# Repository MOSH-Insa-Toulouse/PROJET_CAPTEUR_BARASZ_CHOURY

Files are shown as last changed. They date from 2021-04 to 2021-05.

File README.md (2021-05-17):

# PROJET_CAPTEUR_BARASZ_CHOURY
 
## SOMMAIRE 
* 1 [Introduction](#introduction)
* 2 [Installation de la chaine de mesure](#paragraph2)
* 3 [Modélisation de la carte PCB sur KiCad](#paragraph3)
* 4 [Fabrication du shield et soudure des composants](#paragraph4)
* 5 [Arduino UNO](#paragraph5) 
    *  5.1 [Description du code](#subparagraph5.1) 
    *  5.2 [Bibliothèques Arduino](#subparagraph5.2)
* 6 [Application APK](#paragraph6)
* 7 [Mise en oeuvre du banc de test](#paragraph7)
    *  7.1 [Protocole](#paragraph7.1)
    *  7.2 [Résultats obtenus](#paragraph7.2)
* 8 [Améliorations à apporter](#paragraph8)

--------- 
## Introduction 
2020-2021 : Ce projet a été réalisé dans le cadre de l'unité de formation _"Du capteur au banc de test"_ de 4ième année Génie Physique à l'INSA Toulouse.
L’objectif est la conception d’un capteur de déformation (jauge de déformation) à base de graphite, peu coûteux, flexible, léger, et avant tout écoresponsable. 

Le coloriage au crayon laisse une fine couche de graphite sur le papier. Cette couche de graphite possède un réseau percolé caractéristique. Toute déformation de ce réseau induit une variation de la distance entre les nanoparticules de graphite. Cette dernière est à l’origine de la modification de la conductivité électrique/résistance de la couche de graphite. 

Souhaitant acquérir et exploiter le signal associé à la résistance du capteur, nous avons réalisé un shield PCB, à l’aide du logiciel KiCad contenant un amplificateur transimpédance, des interfaces pour un module bluetooth, un écran OLED, et un encordeur rotatoir. Ce shiled PCB est ensuite inséré sur un microcontrôleur Arduino Uno, programmé à l’aide du logiciel Arduino IDE en C++. Les mesures de résistances sont également transmises par Bluetooth et répertoriées sur notre application android APK créée sur MIT App Inventor. 

La chaîne de mesure fin prête, nous avons mis au point un banc de test permettant l'étude de la variation relative de la résistance de différents type de capteurs lors de déformation en compression et tension. 

--------------------

## Installation de la chaine de mesure 

    - Imprimer le PCB, préalablement designé sur KiCad, grâce à l'empreinte Gerber. 
  
    - Vérifier l'état des pistes. 
  
    - Souder les composants et brancher l'OLED, l'encodeur rotatoir et le module Bluetooth. 
  
    - Connecter le PCB sur la carte Arduino Uno.
  
    - Connecter le microcontrolleur Arduino Uno au PC grâce au cable USB. 
  
    - Ouvrir le programme Arduino (voir dossier Arduino).   
      Sélectionner au préalable le bon port de communication Arduino puis compiler et téléverser le programme. 
  
Les valeurs de résistance/tension sont directement affichées sur l'écran OLED. Grâce à l'encodeur rotatoir, vous pouvez décider d'afficher la grandeur souhaitée. Ces dernières sont aussi disponibles sur le moniteur Arduino.
Vous pouvez aussi télécharger notre application APK pour obtenir directement les valeurs sur votre smartphone grâce à votre connexion Bluetooth. 

-------------------

## Modélisation de la carte PCB sur KiCad 

Réalisation de la carte PCB sur KiCad  
   
    - Creation des symboles de l'OLED, le module bluetooth, l'encodeur rotatoir et le capteur graphite.
      Tous les symboles sont répertoriés dans le dossier KiCad. 

    - Schéma electrique du circuit sur eeschema. Sur ce shéma, vous trouverez un amplificateur transimpédance,
      l'écran OLED, le module Bluetooth et l'encodeur rotatoire. En haut à droite les pins de la carte Arduino
      sont représentées.  
Capture d’écran 2021-04-20 à 10 19 14

    - Routage des pistes sur pcbnew.

Visualisation 2D du shield 

Capture d’écran 2021-04-20 à 10 38 54
   
Visualisation 3D du shield

Capture d’écran 2021-04-20 à 10 42 33

-------------------

## Fabrication du shield et soudure des composants 

Avec l'aide de Mme Cathy Crouzet, nous avons fabriqué la carte PCB modélisée au préalable sur le logiciel KiCad. Notre carte PCB est constituée d'une plaque isolante d'epoxy recouverte d'une très fine feuille de cuivre. Une couche de résine photosensible est déposée sur ce support epoxy cuivré.

Tout d'abord, le tracé de notre modélisation PCB est imprimé sur un support transparant aux ultraviolets de type papier calque : on obtient le masque (ou typon). Celui ci est placé sur la plaquette epoxy, dans l'insoleuse à tube UV, en prenant soin de poser le côté encré au contact du cuivre. Lors de l'insolation de la plaque (réalisée en 1'30"- 2'30"), les parties du typon correspondant aux pistes du circuit empêchent les UV d'atteindre la surface sensible.   
La plaque est ensuite plongée quelques secondes dans un liquide appelé révélateur. Celui ci dissout la résine exposée aux UV lors de l'insolation. A la fin de cette étape, la résine est seulement conservée dans les zones destinées aux pistes de notre circuit.

Après une étape de rinçage à l'eau courante, la plaquette doit par la suite être gravée. Pour cela, nous la plongeons dans un bain de perchlorure de fer pendant 10 minutes environ. Les parties de cuivre non protégées par la résine photosensible sont ici dissoues. Enfin, la dernière étape du processus consiste à retirer l'excès de résine en utilisant de l'acétone. 

La carte PCB ainsi obtenue est fin prête pour les étapes de perçage et de mise en place des composants. 

  * Perçage des trous de la plaque obtenugrâce à une perçeuse électrique 
Nous perçons des trous de diamètre égale à :
      * 0.8mm pour l'AOP, les résistances et les capacités.
      * 1mm pour les connecteurs de l'Arduino, le module Bluetooth, l'écran OLED, l'encodeur rotatoire et les pinces du capteur.
 
  * Soudure des composants
 
Les composants sont soudés sur la carte PCB à l'aide d'un fer à souder. 
 
----------------------

## Arduino UNO 

### Description du code 

Le code Arduino permet de lire les valeurs de tension du capteur de graphite et calcule la valeur de résistance correspondante. Il assure l'affichage des valeurs de tension et de résistance sur un écran OLED. De plus, le code permet la gestion d'un menu via l'encodeur rotatoire: l'utilisateur peut décider d'afficher la valeur de la résistance ou bien celle de la tension. 

Le code permet aussi de communiquer par Bluetooth avec le télephone portable grâce. Il envoie la mesure de la tension du capteur de graphite par Bluetooth. 

### Bibliothèques Arduino 

Afin d'utiliser le code Arduino, il vous faudra au préalable télécharger des bibliothèques Arduino.

À installer depuis l'IDE ou GitHub :

- Adafruit GFX Library : https://github.com/adafruit/Adafruit-GFX-Library
- Adafruit SSD1306 : https://github.com/adafruit/Adafruit_SSD1306
- Adafruit BusIO : https://github.com/adafruit/Adafruit_BusIO  

Vous pouvez aussi télécharger ces bibliothèques direcetement sur l'application Arduino

1) Dans l’IDE Arduino cliquez sur "croquis", allez sur "inclure un bibliothèque" puis cliquez sur  "Gerer les bibliothèques".  

Capture d’écran 2021-04-21 à 09 37 15

2) Une fenêtre apparait. Tappez le nom de la bibliothèques que vous voulez ajouter dans la barre de recherche et cliquez sur  "Installer".Fermez la fenêtre.  
   
Capture d’écran 2021-04-21 à 09 36 37

3) Dans l’IDE Arduino cliquez sur "croquis", allez sur "inclure un bibliothèque". A la fin dans les "bibliothèques contribuées" doit se trouver votre biblothèques téléchargée.  

Capture d’écran 2021-04-21 à 09 40 34

4) Afin de savoir comment fonctionne la bibliothèque installée, vous pourrez vous servir de la page d’aide qui accompagne généralement la bibliothèque ou alors vous aider des exemples fournis avec celle-ci disponible ici :  

Capture d’écran 2021-04-21 à 09 43 44

------------------------------

## Application APK 

L'application APK est une applictaion pour smartphone utilisant le système d'exploitation Android. 
Vous pouvez télecharger l'application grâce au fichier .apk qui vous est fourni dans notre dossier APK Bluetooth.  
Si vous souhaitez modifier l'application, vous pouvez utiliser le fichier .aia sur l'application en ligne _MIT APP INVENTOR_.  

Notre application est à mettre en relation avec le code Arduino développé pour mesurer la tension de la couche de graphite. L'application permet de :
  * se connecter à un module Bluetooth.
  * une fois connecté, relever la  valeur de la tension de la couche de graphite envoyée par Bluetooth.
  * calculer la résistance correspondante.
  * afficher ces deux valeurs de tension et de résistance
  * tracer un graphe décrivant l'évolution de la tension au cours du temps.  

app

----------------------------

## Mise en oeuvre du banc de test  

### Protocole 

Le protocole du banc de test est détaillé dans le fichier "Protocole du banc de test". Veuillez trouver ci joint le lien de ce fichier :https://github.com/MOSH-Insa-Toulouse/PROJET_CAPTEUR_BARASZ_CHOURY/blob/c4a42f93ef4b2496bb2e2b371ca4b9b335598a01/Banc%20de%20test/Protocole%20de%20notre%20banc%20de%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

### Résultats obtenus 

Résultats obtenus sont détaillés au lien suivant : https://github.com/MOSH-Insa-Toulouse/PROJET_CAPTEUR_BARASZ_CHOURY/blob/7fd93865a4fc5e2c620f3dd2ebc7bdd68492d652/Banc%20de%20test/R%C3%A9sultats%20Banc%20de%20Test.x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 

Les analyses de nos résultats : https://github.com/MOSH-Insa-Toulouse/PROJET_CAPTEUR_BARASZ_CHOURY/blob/7fd93865a4fc5e2c620f3dd2ebc7bdd68492d652/Banc%20de%20test/Analyse%20de%20nos%20r%C3%A9sultats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 

----------------------------

## Améliorations à apporter  
 
Notre banc de test présente certaines limites. On peut critiquer notamment : 
   - le dépôt de graphite sur le papier : on ne peut maitriser la quantité de graphite déposée sur le papier, la précision du coloriage.
   - la non répétabilité de la mesure. En effet, entre chaque série de mesures, les déformations appliquées peuvent varier: le banc de test ne permet pas d’appliquer une       déformation identique. On pourrait envisager un banc de test fonctionnant avec un servomoteur par exemple. Ce système permet de générer des contraintes avec des consignes d’angles bien présice et d'obtenir, de ce fait, une meilleure reproductibilité. 
   - la déformation irréversible du capteur entre chaque série de mesures. 

Notre carte shield peut être également améliorée. En effet, afin de pouvoir lire une plus grande plage de résistance tout en ayant des mesures stables, il faudrait pouvoir changer le gain du circuit transimpédance c'est à dire modifier la résistance R2 (voir schéma KiCad ). Cependant nous l'avons soudée sur le circuit PCB. Il aurait donc fallu : 
    
   - ne pas souder cette résistance pour pouvoir mettre des résistances différentes
   - souder une résistance variable (potentiomètre).   

Un code Arduino plus complet pourrait également être développé. Si nous travaillons avec une résistance R2 variable, le code doit prendre en compte la modification de la valeur de R2. Le code Arduino pourrait gérer un encodeur rotatoire permttant de modifier la valeur de R2 dans le code.

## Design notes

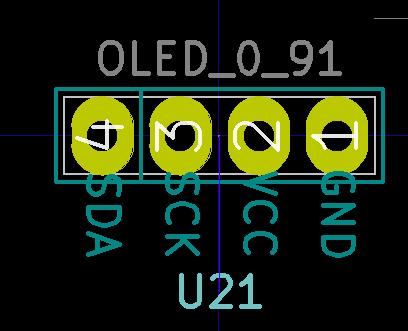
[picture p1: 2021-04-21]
KiCad/OLED/empreinte_OLED.png

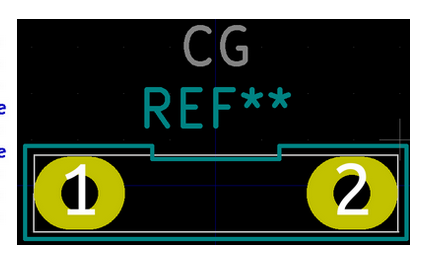
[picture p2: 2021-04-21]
KiCad/Capteur/empreinte_capteur.png

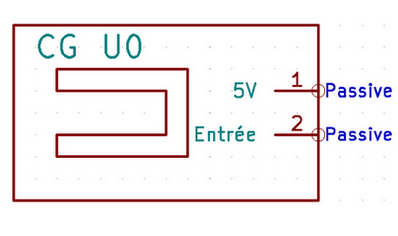
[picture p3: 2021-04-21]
KiCad/Capteur/schema_capteur.png

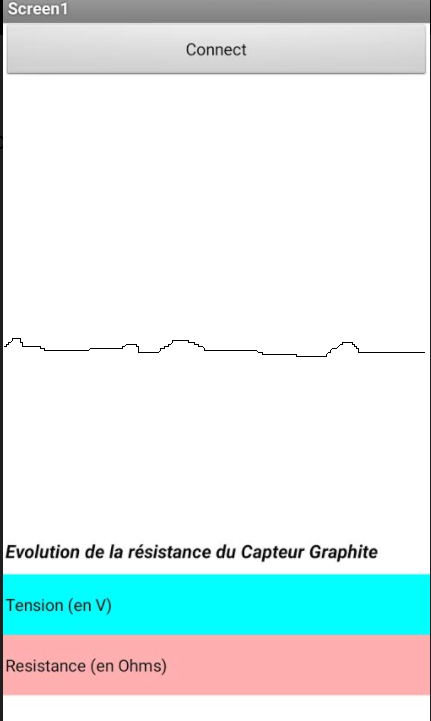
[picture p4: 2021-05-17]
APK Bluetooth/app.png

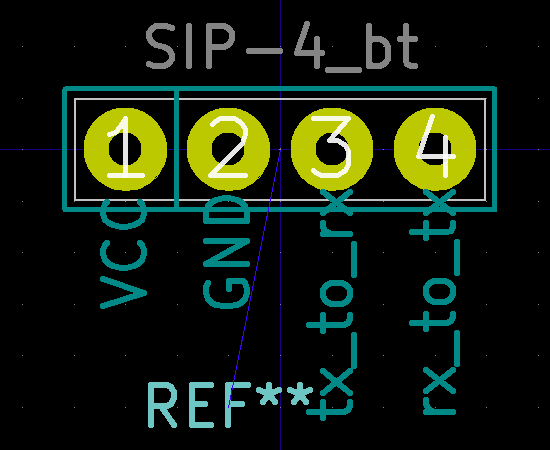
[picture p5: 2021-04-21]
KiCad/Module bluetooth/empreinte_module_bt.png

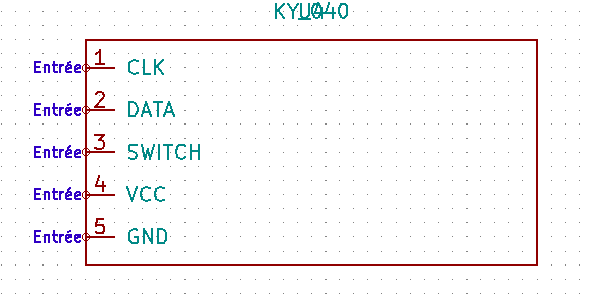
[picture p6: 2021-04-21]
KiCad/Encodeur Rotatoir/schema_encodeur.png

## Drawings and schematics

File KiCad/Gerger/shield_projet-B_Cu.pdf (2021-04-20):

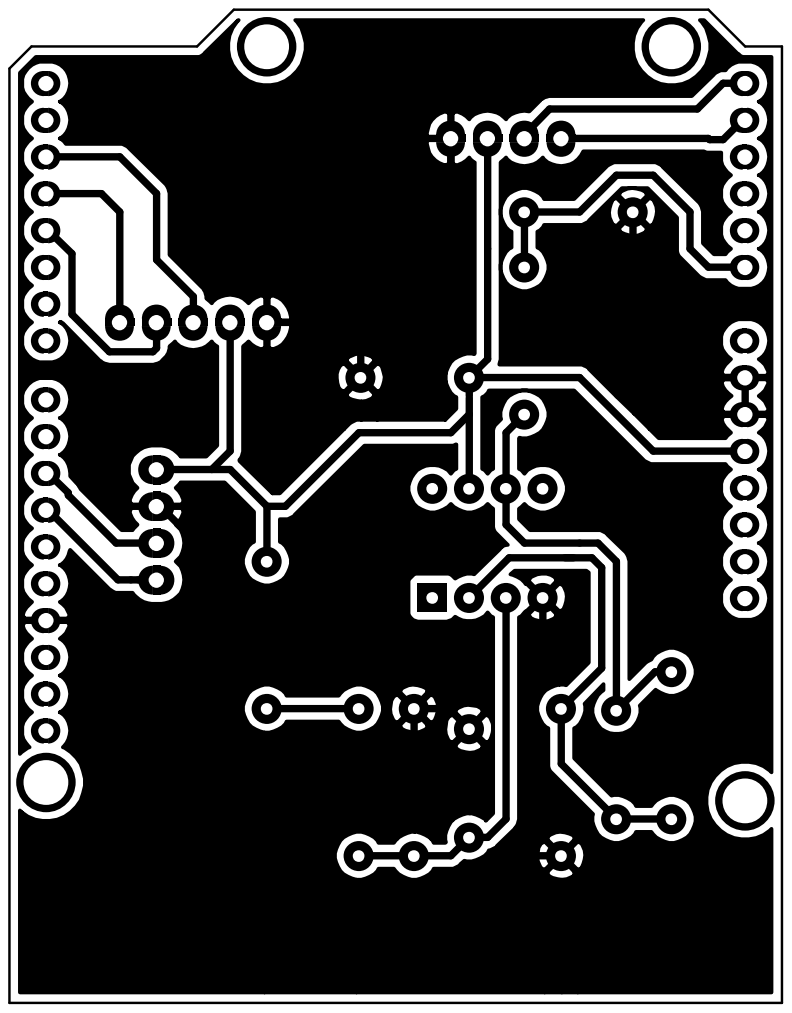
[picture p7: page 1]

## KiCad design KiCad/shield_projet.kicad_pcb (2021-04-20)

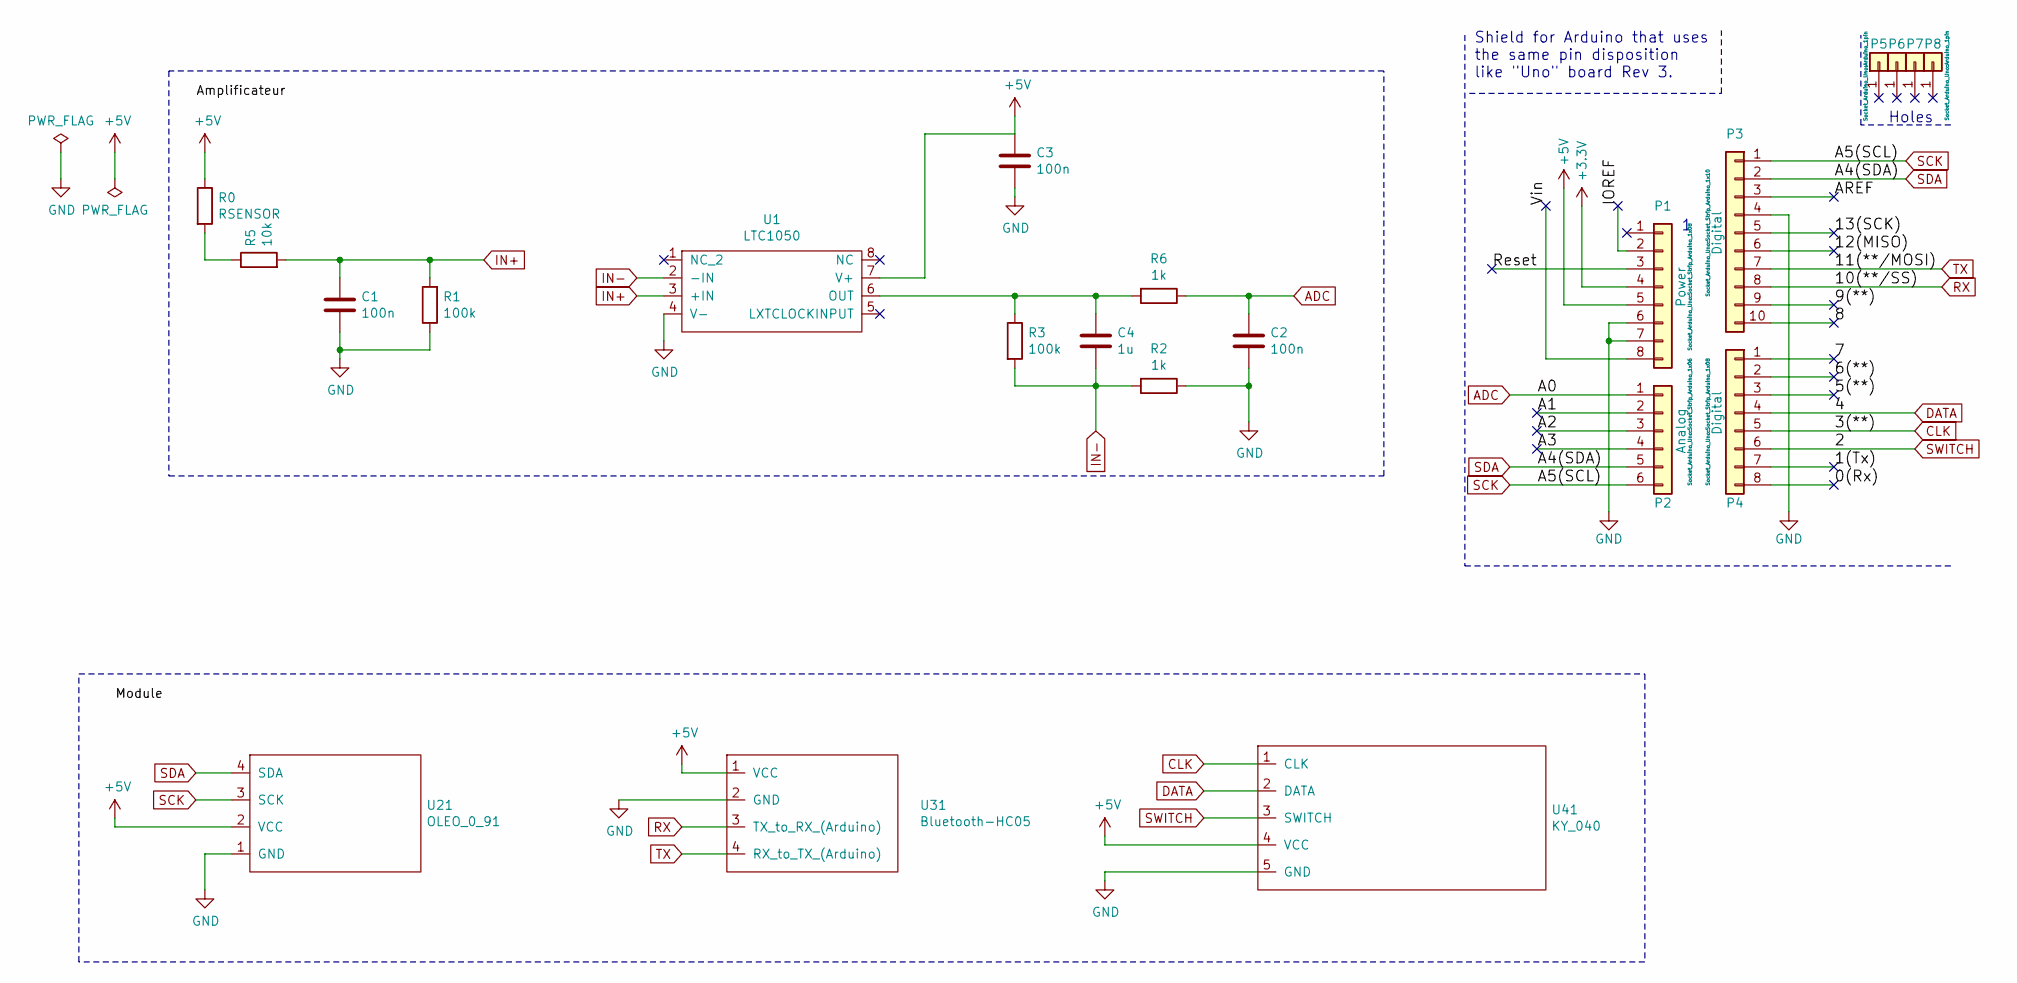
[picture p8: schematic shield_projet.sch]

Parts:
C1, C2, C3: 100n; C_Axial_L5.1mm_D3.1mm_P7.50mm_Horizontal
C4: 1u; C_Axial_L5.1mm_D3.1mm_P7.50mm_Horizontal
P1: Power; Socket_Strip_Arduino_1x08
P2: Analog; Socket_Strip_Arduino_1x06
P3: Digital; Socket_Strip_Arduino_1x10
P4: Digital; Socket_Strip_Arduino_1x08
P5, P6, P7, P8: CONN_01X01; Arduino_1pin
R0: RSENSOR; R_Axial_DIN0207_L6.3mm_D2.5mm_P10.16mm_Horizontal
R1, R3: 100k; R_Axial_DIN0207_L6.3mm_D2.5mm_P10.16mm_Horizontal
R2, R6: 1k; R_Axial_DIN0207_L6.3mm_D2.5mm_P10.16mm_Horizontal
R5: 10k; R_Axial_DIN0207_L6.3mm_D2.5mm_P10.16mm_Horizontal
U1: LTC1050; DIP-8_296
U21: OLEO_0_91; SIP-4
U31: Bluetooth-HC05; SIP-4_bt
U41: KY_040; SIP-5

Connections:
+3V3: P1.4
+5V: C3.1, P1.5, R0.1, U1.7 (V+), U21.2 (VCC), U31.1 (VCC), U41.4 (VCC)
/0(Rx): P4.8
/1(Tx): P4.7
/5(**): P4.3
/6(**): P4.2
/7: P4.1
/8: P3.10
/9(**): P3.9
/12(MISO): P3.6
/13(SCK): P3.5
/A1: P2.2
/A2: P2.3
/A3: P2.4
/AREF: P3.3
/IOREF: P1.2
/Reset: P1.3
/Vin: P1.8
ADC: C2.1, P2.1, R6.1
CLK: P4.5, U41.1 (CLK)
DATA: P4.4, U41.2 (DATA)
GND: C1.2, C2.2, C3.2, P1.6, P1.7, P3.4, R1.1, R2.1, U1.4 (V-), U21.1 (GND), U31.2 (GND), U41.5 (GND)
IN+: C1.1, R1.2, R5.2, U1.3 (+IN)
IN-: C4.2, R2.2, R3.2, U1.2 (-IN)
unnamed: C4.1, R3.1, R6.2, U1.6 (OUT)
unnamed: R0.2, R5.1
RX: P3.8, U31.3 (TX_to_RX_(Arduino))
SCK: P2.6, P3.1, U21.3 (SCK)
SDA: P2.5, P3.2, U21.4 (SDA)
SWITCH: P4.6, U41.3 (SWITCH)
TX: P3.7, U31.4 (RX_to_TX_(Arduino))

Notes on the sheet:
Holes
Shield for Arduino that uses the same pin disposition like "Uno" board Rev 3.

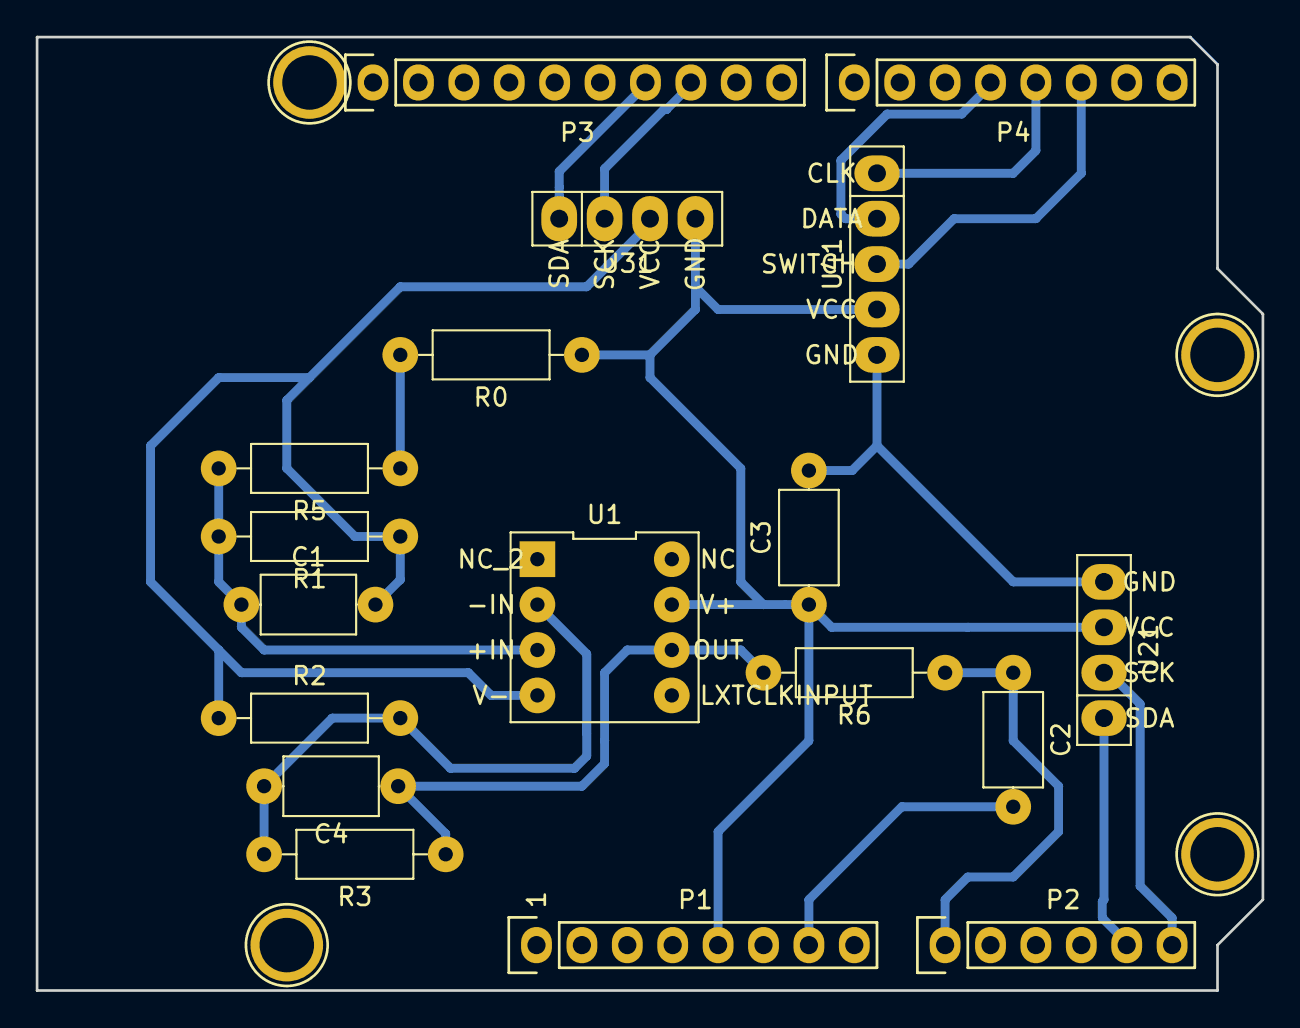
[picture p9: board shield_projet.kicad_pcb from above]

Board: 2 copper layers, 68.6 x 53.3 mm, 22 parts (0 on the bottom side), 14 nets.

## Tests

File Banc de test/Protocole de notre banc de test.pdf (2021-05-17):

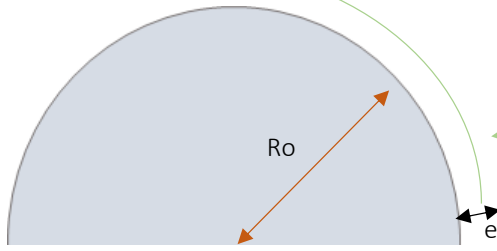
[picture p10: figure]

Ro : rayon de courbure du demi-cylindre à mesurer à l’aide d’une règle graduée.

### Protocole de notre banc de test

### Objectifs :

Nous souhaitons étudier les variations relatives de résistance de notre capteur à base de graphite lors de l’application de déformations en compression et tension. Les mesures seront effectuées avec plusieurs types de crayons à papier (HB, B...) classés suivant leur concentration en graphite. A terme, nous obtiendrons les courbes de sensibilités des différents capteurs. Nous déterminerons, finalement, le capteur le plus sensible que l’on pourrait élaborer.

### Présentation et brève description du matériel :

- Capteur à base de graphite (colorié avec différents types de crayon à papier).
- Carte Shield créée sous le logiciel KiCAD. Un module OLED est branché sur ce PCB pour interfacer les valeurs de résistance/tension du capteur. De même, un encodeur rotatoire est inséré sur la carte pour sélectionner l’affichage de valeur de tension ou bien de résistance.
- Carte Aduino UNO. La carte Shield est pluggée sur l’Arduino.
- Cable USB pour relier la carte Arduino au PC.
- Support de déformation en plastique. Il est composé de plusieurs « demi-cylindres » , placés côte à côte, de rayons différents. Il est possible de mesurer directement le rayon de ces « demi-cylindres ». Ce support permet l’application de différentes contraintes (compression ou en tension) du capteur à base de graphite.

### Relation entre le rayon de courbure du support et la déformation :

Schéma en coupe du support en plastique

Capteur de
graphite placé
à la surface du

e
O

La déformation en e/2 est donnée par la formule suivante :

ε (

e
2

) = −

e
2Ro + e

Connaissant l’épaisseur du capteur de papier (0,3mm) et le rayon de courbure, nous pouvons calculer la déformation de notre capteur à base de graphite.

### Protocole du banc de test en utilisant un capteur « colorié » avec un type de crayon à papier donné :

- Connecter le capteur à base de graphite à la carte Shield grâce à des pinces en cuivre.
- Déterminer la résistance Ro de la couche de graphite soumise à aucune déformation : on lit directement la valeur de la résistance sur l’écran OLED. Si cette valeur n’est pas mesurable, on peut rajouter du graphite sur le capteur.
- Mesurer à l’aide d’une règle graduée le rayon de courbure du premier demi-cylindre du support de déformation.
- Plaquer le capteur à la surface de ce même demi-cylindre de déformation.
- Lire à valeur de résistance sur l’écran OLED.
- Répéter les mêmes opérations pour les autres demi-cylindres de déformation. On prendra soin de mesurer la résistance « au repos » Ro après chaque insertion du capteur sur un demi-cylindre. Celle-ci est amené à varier. En effet, dès la première mesure, le capteur entre dans le domaine de non-détérioration :ses caractéristiques métrologiques sont modifiées. Précisément, la résistance d'offset varie après chaque nouvelle contrainte appliquée.
- Répertorier toutes les valeurs obtenues sur le fichier Excel.
- Tracer la courbe de sensibilité ∆R/R0=f(ε).

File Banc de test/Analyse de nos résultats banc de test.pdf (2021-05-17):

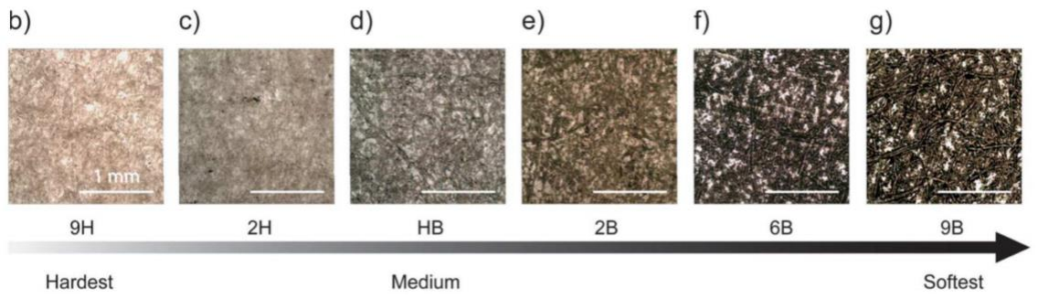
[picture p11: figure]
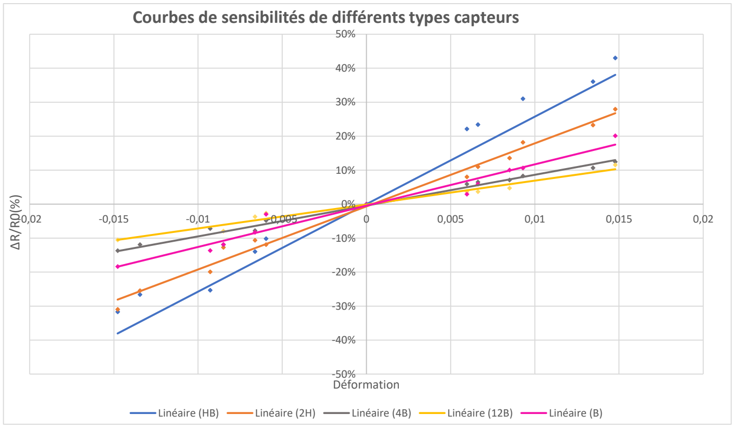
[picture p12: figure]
Déformation; Linéaire (HB); Linéaire (2H); Linéaire (4B); Linéaire (12B); Linéaire (B)

### Courbes de sensibilités de différents types capteurs

## Analyse des résultats banc de test

Nous avons effectué une série de mesure avec des capteurs de déformation coloriés avec des crayons à papier 12B, 4B, B, HB et 2H.

Figure 1 : Illustration
de la différence de
couleur de la trace en
fonction du type de
crayon à papier

D’après la figure 1 présentée ci-dessus, le crayon à papier 9B laisse une trace sombre très marquée sur la feuille de papier alors que la trace obtenue avec le crayon 9H est plus claire et douce. La différence de couleur provient de la différence de concentration en particules de graphite entre ces 2 crayons à papier. En effet, plus le crayon laisse une trace sombre sur le papier, plus la concentration en particule de graphite de ce dernier est importante.

Résultat de notre banc de test :

( voir fichier Excel « Résultat banc de test » pour visualiser toutes les courbes en détail)

Analyse :

D’une part, pour chaque capteur, la variation relative de résistance évolue linéairement en fonction de la déformation.

D’autre part, lors de l’application d’une même déformation, la variation relative de résistance est la plus faible pour le capteur colorié avec le crayon à papier 12B (possédant la plus forte concentration en graphite). Pour une même déformation appliquée, plus la concentration en graphite du crayon à papier diminue, plus la variation de résistance relative mesurée avec le capteur associé augmente.

En effet, lorsque le capteur est soumis à une déformation en tension, le réseau percolé de la couche de graphite déposée sur la feuille de papier se trouve directement étendu. Cette déformation induit l’éloignement des particules de graphite au sein du réseau. Certains chemins de percolation sont par conséquent rompus. Plus la concentration en particules de graphite est faible, plus le nombre de chemins de percolation en mesure de conduire le courant est faible : la résistance de la couche de graphite augmente.

De même, lorsque le capteur est soumis à une déformation en compression, le réseau percolé de la couche de graphite déposée sur la feuille de papier se trouve directement comprimé. Cette déformation induit le rapprochement des particules de graphite au sein du réseau. De nouveaux chemins de percolation apparaissent. Plus la concentration en particules de graphite est faible, plus le nombre de chemins de percolation total conduisant le courant est faible : la résistance relative de la couche de graphite augmente. Nos résultats semblent donc bien concorder avec la théorie.

Finalement, ici la pente des droites ∆R/R0=f(ε) correspond à la sensibilité du capteur associé. Plus la concentration en graphite du crayon à papier diminue, plus la sensibilité du capteur associé augmente. Dans notre cas, le capteur colorié avec le crayon à papier 12B possède la plus grande sensibilité. C’est donc le capteur de déformation le plus sensible, performant que nous pouvons actuellement concevoir.

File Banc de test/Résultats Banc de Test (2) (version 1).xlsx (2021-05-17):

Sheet: 12B ok
Épaisseur du papier (m) | Rayon de Courbure (m) | Déformation | Résistance B (Mohms) | Résistance B/R0 | ∆R (Mohms) | ∆R/R0
0.0003 | 1.79e+307 | 0 | 19 | 1 | 0 | 0%
 | 0.025 | 0.005964214712 | 19.7 | 1.036842105 | 0.7 | 3.684210526%
 | 0.025 | -0.005964214712 | 18.5 | 0.9736842105 | -0.5 | -2.631578947%
 | 0.01 | 0.01477832512 | 21.2 | 1.115789474 | 2.2 | 11.57894737%
 | 0.01 | -0.01477832512 | 17 | 0.8947368421 | -2 | -10.52631579%
 | 0.0175 | 0.008498583569 | 19.9 | 1.047368421 | 0.9 | 4.736842105%
 | 0.0175 | -0.008498583569 | 17.5 | 0.9210526316 | -1.5 | -7.894736842%
 | 0.0225 | 0.006622516556 | 19.7 | 1.036842105 | 0.7 | 3.684210526%
 | 0.0225 | -0.006622516556 | 18.3 | 0.9631578947 | -0.7 | -3.684210526%
 | Min | Max
 | 18.8 | 19.5
 | 21.3 | 21.6
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

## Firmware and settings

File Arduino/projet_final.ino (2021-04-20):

/**********************************************************
************** DEFINITION DES BIBLIOTHEQUES **************
**********************************************************/


#include <SoftwareSerial.h>
#include <SPI.h>
#include <Wire.h>
#include <Adafruit_GFX.h>
#include <Adafruit_SSD1306.h>


/**********************************************************
****************** DEFINITION DES PORTS ******************
**********************************************************/

#define rxpin 11
#define txpin 10
#define baudrate 9600

SoftwareSerial myserial (rxpin,txpin);

//CAPTEUR
#define analog_port 0
#define Periode 50 //envoie des données toute les 50ms

#define SCREEN_WIDTH 128 // OLED display width, in pixels
#define SCREEN_HEIGHT 32 // OLED display height, in pixels

// Declaration for an SSD1306 display connected to I2C (SDA, SCL pins)
// The pins for I2C are defined by the Wire-library. 
// On an arduino UNO:       A4(SDA), A5(SCL)
// On an arduino MEGA 2560: 20(SDA), 21(SCL)
// On an arduino LEONARDO:   2(SDA),  3(SCL), ...
#define OLED_RESET     4 // Reset pin # (or -1 if sharing Arduino reset pin)
#define SCREEN_ADDRESS 0x3C ///< See datasheet for Address; 0x3D for 128x64, 0x3C for 128x32
Adafruit_SSD1306 display(SCREEN_WIDTH, SCREEN_HEIGHT, &Wire, OLED_RESET);

#define encodeur0PinA 2 // CLK
#define encodeur0PinB 3 // DATA
#define Switch 4 // switch


/**********************************************************
******************* VARIABLES GLOBALES *******************
**********************************************************/

double tension;
double resistance;
unsigned long temps_ref;

volatile unsigned int encodeur0Pos = 0;
volatile unsigned int choice =0;
// 0) resistance
// 1) tension

volatile unsigned int Menu = 0;
// 0) mesure on
// 1) mesure off

bool SwitchState= HIGH;
bool SwitchLast= LOW;

/**********************************************************
*********************** FONCTIONS ************************
**********************************************************/

void affichage_tension (double tension)
{
  //configuration de l'écran
  display.clearDisplay();
  display.setTextSize(2);
  display.setTextColor(WHITE);

  //Affichage de la tension
  Serial.println(tension);
  display.setCursor(30,0);
  display.println(F("tension"));
  display.setCursor(40,17);
  display.println(tension);
  display.setCursor(90,17);
  display.println(F("V"));
  display.display();
}


void affichage_resistance (double resistance)
{
  //configuration de l'écran
  display.clearDisplay();
  display.setTextSize(2);
  display.setTextColor(WHITE);

  //Affichage de la tension
  Serial.println(resistance);
  display.setCursor(5,0);
  display.println(F("resistance"));
  display.setCursor(0,17);
  display.println(resistance);
  display.setCursor(65,17);
  display.println(F("MOhms"));
  display.display();
}

void Menu_OLED ()
{
  if (choice==0)
    {
      choice = 1;
    }
    else
    {
      choice = 0;
      
    }
}


/**********************************************************
****************** PROGRAMME PRINCIPAL *******************
**********************************************************/

void setup()
{
//ouverture des ports 
pinMode (rxpin, INPUT);
pinMode (txpin, OUTPUT);

pinMode (encodeur0PinA,INPUT);
digitalWrite(encodeur0PinA,HIGH);
pinMode (encodeur0PinB,INPUT);
digitalWrite(encodeur0PinB,HIGH);
temps_ref=millis();


myserial.begin(baudrate);
Serial.begin(baudrate);

display.begin(SSD1306_SWITCHCAPVCC, SCREEN_ADDRESS);

 /* if(!display.begin(SSD1306_SWITCHCAPVCC, SCREEN_ADDRESS)) {
    Serial.println(F("SSD1306 allocation failed"));
    for(;;); // Don't proceed, loop forever
  }

  // Show initial display buffer contents on the screen --
  // the library initializes this with an Adafruit splash screen.
  display.display();
  delay(2000); // Pause for 2 seconds

  // Clear the buffer*/

//Ecran de demarrage

display.clearDisplay();
display.setTextSize(2);
display.setTextColor(WHITE);
display.setCursor(5,10);
display.println(F("Sasa & Lea"));
display.display();
delay(2000);

}

void loop()
{
 
 tension = analogRead(analog_port);

//Bluetooth  
 if (abs(millis()-temps_ref) > Periode)
 {
 byte V = map(tension,0,1023,0,255);
 myserial.write(V);
 }
 temps_ref=millis();
 
 
 tension=tension*5/1024;
 resistance = (1.0+100.0)*100000.0*(5.0/tension)-100000.0-10000.0;
 
 delay(25);

  //Gestion du bouton de l'encodeur rotatoir
  SwitchState = digitalRead(Switch);
  if (SwitchState == HIGH && SwitchLast == LOW && Menu ==0) 
  {
    Menu=1;
    attachInterrupt(digitalPinToInterrupt(encodeur0PinB), Menu_OLED, RISING);
    delay(500);//debounce 
  }
  else if (SwitchState == HIGH && SwitchLast==LOW && Menu ==1) 
  {
    Menu=0;
    detachInterrupt(digitalPinToInterrupt(encodeur0PinB)); 
    delay(500);//debounce
  }
  SwitchLast = SwitchState;

  //Gestion de l'Affichage sur l'écran OLED
  switch (Menu)
  {
    case 0 :
      switch (choice)
    {
      case 0 : 
      affichage_resistance(resistance/1000000.0);
      break;
  
      case 1 :
      affichage_tension (tension) ;
      break;
    }
    break;
    
    case 1 :
      switch (choice)
    {
      case 0 : 
      //Configuration de l'écran
      display.clearDisplay();
      display.setTextSize(1); 
      display.setTextColor(WHITE);
  
      display.setCursor(5, 0);
      display.println(F(" -> Resistance"));
      display.setCursor(30, 17);
      display.println(F("Tension"));
      display.display();
      break;
  
      case 1 :
      //Configuration de l'écran
      display.clearDisplay();
      display.setTextSize(1); 
      display.setTextColor(WHITE);
  
      display.setCursor(30, 0);
      display.println(F("Resistance"));
      display.setCursor(5, 17);
      display.println(F(" -> Tension"));
      display.display();
      break;
    }
    break;
  } 
}

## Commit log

2021-04-20 Create code Arduino
2021-04-21 Rename KiCad/module bluetooth/a to KiCad/Module bluetooth/a
2021-04-28 banc de test
